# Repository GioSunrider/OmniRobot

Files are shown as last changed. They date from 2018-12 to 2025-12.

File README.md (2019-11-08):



# OmniRobot
Diseño e implementación de un robot omnidireccional para fines de entretenimiento. Proyecto de Final de Grado de Ingeniería Electrónica Industrial y Automática por la Universidad Carlos III de Madrid. 

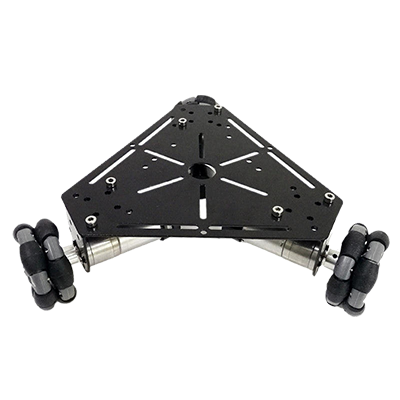
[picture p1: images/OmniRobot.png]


## BOM (Build Of Materials)

### Three Wheel Robot

* [100:1 Metal Gearmotor 37Dx57L mm](https://www.pololu.com/product/1106/specs)
* [Pololu Dual MC33926 Motor Driver Carrier](https://www.pololu.com/product/1213)
* [Pro Micro - 5V/16MHz](https://www.sparkfun.com/products/12640)
* [Omni Wheel 40x28mm Plástico](https://hobbyking.com/es_es/40x28mm-plastic-omni-wheel-2pcs-bag.html)
* Partes Impresas en **PETG** de [Fiberlogy](https://fiberlogy.com/en/fiberlogy-filaments/filament-pet-g/)
* [Laser Diodo 5V](http://es.aliexpress.com/item/2009851151.html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,searchweb201602_1,searchweb201603_55)
* [Convertidor DC-DC 5V](https://es.aliexpress.com/item/33011856834.html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,searchweb201602_1,searchweb201603_55)
* [Servo motor 90º](https://es.aliexpress.com/item/32958137557.html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,searchweb201602_1,searchweb201603_55) 

### Four Wheel Robot

* [30:1 Metal Gearmotor 37Dx57L mm](https://www.pololu.com/product/4742)
* [Pololu Dual MC33926 Motor Driver Carrier](https://www.pololu.com/product/1213)
* [Pro Micro - 5V/16MHz](https://www.sparkfun.com/products/12640)
* Partes Impresas en **PETG** de [Fiberlogy](https://fiberlogy.com/en/fiberlogy-filaments/filament-pet-g/)
* [Laser Diodo 5V](http://es.aliexpress.com/item/2009851151.html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,searchweb201602_1,searchweb201603_55)
* [Convertidor DC-DC 5V](https://es.aliexpress.com/item/33011856834.html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,searchweb201602_1,searchweb201603_55)
* [Servo motor 90º](https://es.aliexpress.com/item/32958137557.html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,searchweb201602_1,searchweb201603_55) 

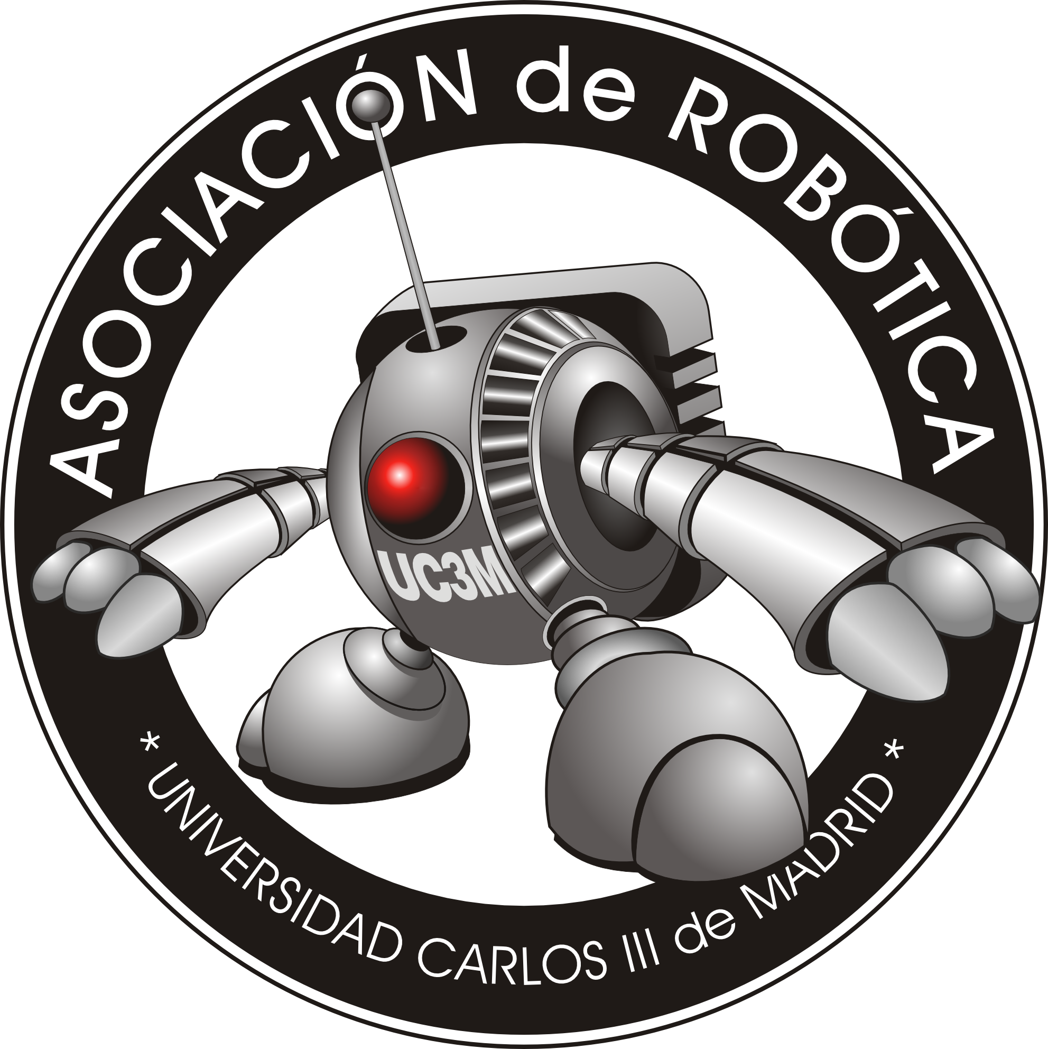
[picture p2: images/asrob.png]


## Contributors

 - Tutored by [@David-Estevez](https://github.com/David-Estevez)
 - [Asociación de Robótica de la Universidad Carlos III de Madrid](https://asrob.uc3m.es/)

## License 



This robot is licensed under a [Creative Commons Attribution-ShareAlike 4.0 International License](http://creativecommons.org/licenses/by-sa/4.0/). Please read the LICENSE files for more details.

Este robot tiene una licencia [Creative Commons Attribution-ShareAlike 4.0 International License](http://creativecommons.org/licenses/by-sa/4.0/). Por favor, lea los ficheros LICENSE para más detalles

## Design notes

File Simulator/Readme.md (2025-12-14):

1. Instalar Processing:

  Descarga Processing desde https://processing.org/download
  
  Instálalo en tu computadora

2. Ejecutar el simulador:

  Copia el código del simulador en un nuevo sketch de Processing
  
  Guarda el sketch con nombre "Robot3W_Simulador"
  
  Haz clic en el botón "Run" (triángulo)

3. Probar controles:

  Usa WASD para mover el robot
  
  Q/E para rotar
  
  ESPACIO para activar motores
  
  X para desactivar
  
  L para láser
  
  R para reset

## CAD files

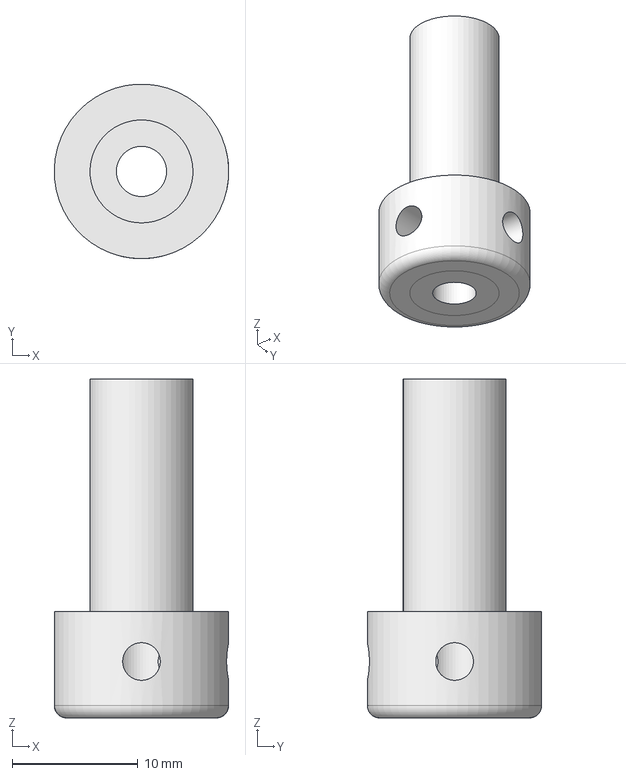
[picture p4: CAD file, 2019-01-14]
parts/Acoplamiento Motores (1)/AcoplamientoParte1.FCStd
13.9 x 13.9 x 27.0 mm

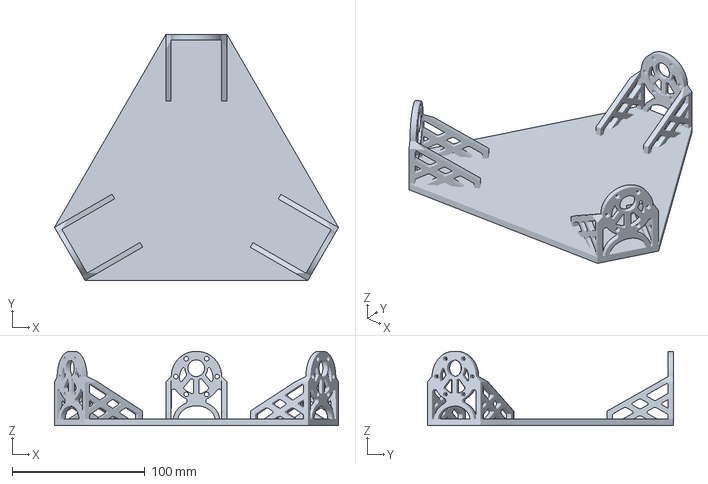
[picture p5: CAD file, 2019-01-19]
parts/Chasis (1)/ChasisV2_repaired.3mf
213.7 x 185.1 x 56.0 mm

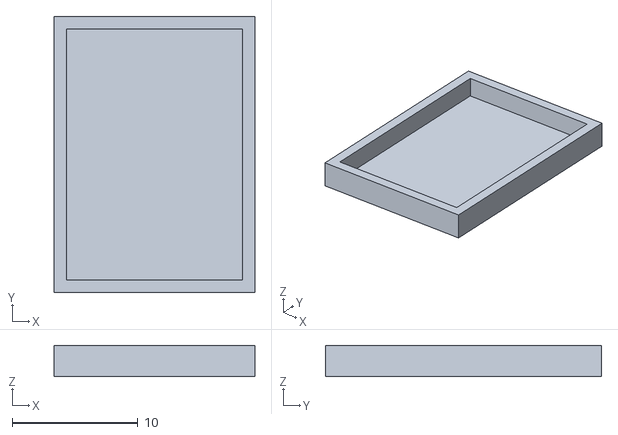
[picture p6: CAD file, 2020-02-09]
parts/Parts_Final/Disipador_BWP4.stl
16.0 x 22.0 x 2.50

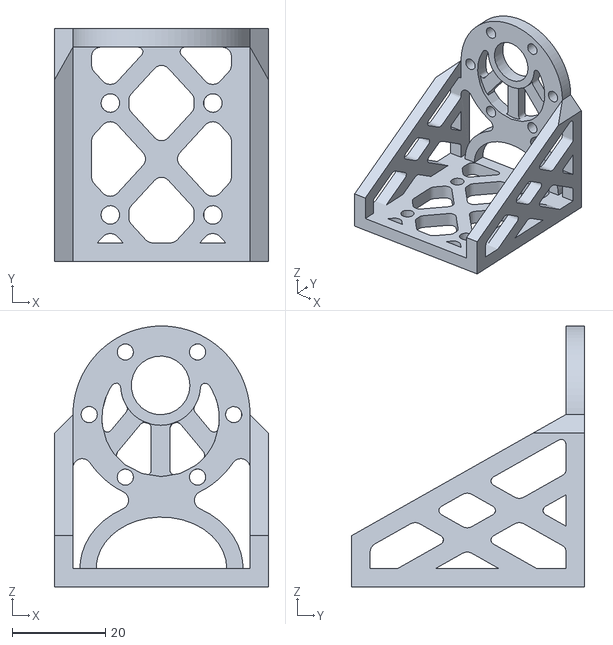
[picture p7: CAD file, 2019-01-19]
parts/Chasis (1)/Motor Holder V2.stl
46.0 x 50.0 x 56.0

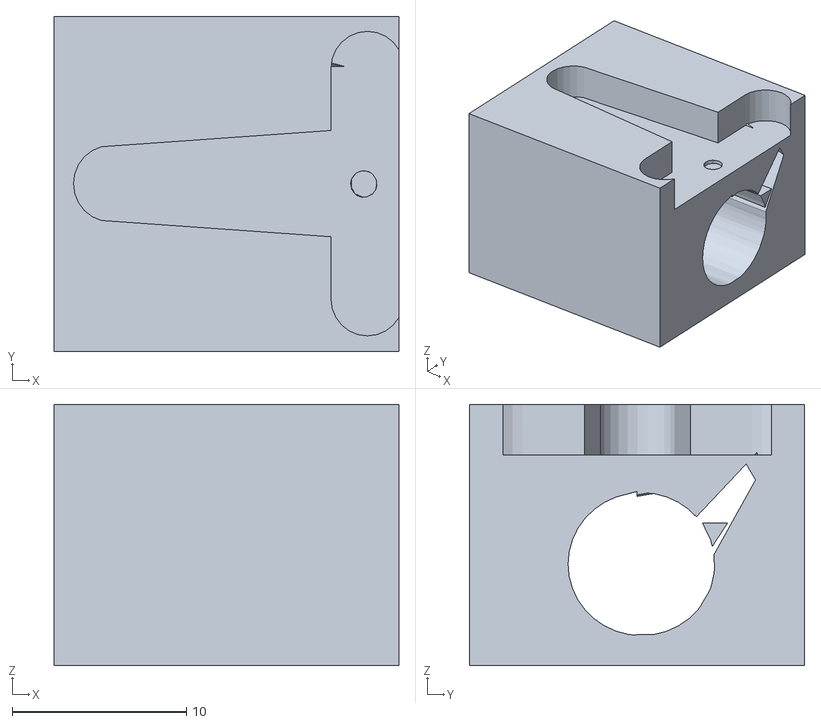
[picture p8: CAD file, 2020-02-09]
parts/Parts_Final/Laser_servo_Mount.stl
19.8 x 19.2 x 15.0

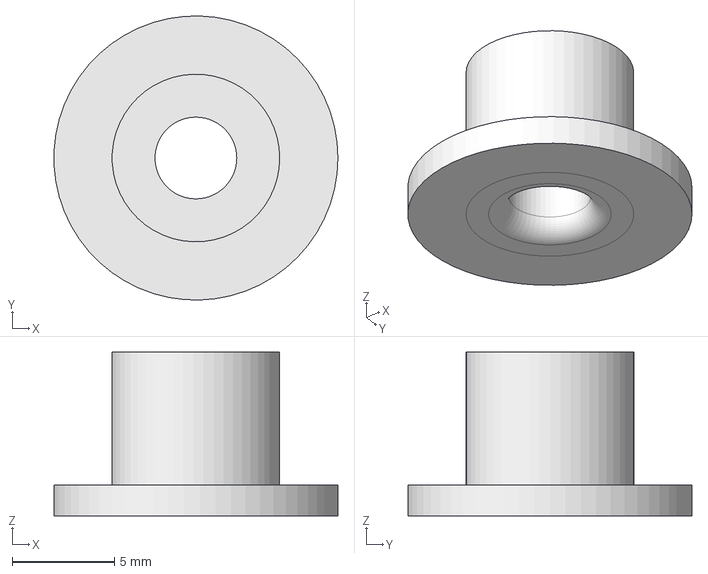
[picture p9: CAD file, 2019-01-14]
parts/Acoplamiento Motores (1)/AcoplamientoParte2.FCStd
13.9 x 13.9 x 8.00 mm

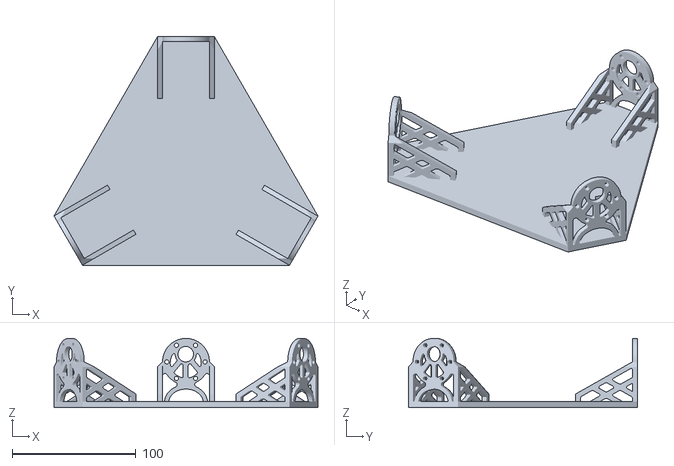
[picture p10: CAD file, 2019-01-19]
parts/Chasis (1)/ChasisV2.stl
213.7 x 185.1 x 56.0

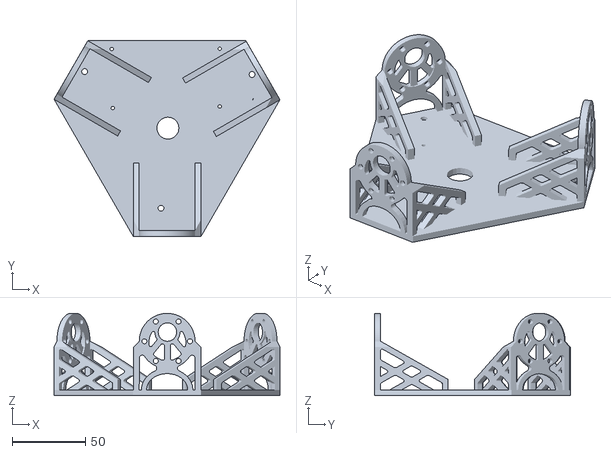
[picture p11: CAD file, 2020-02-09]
parts/Parts_Final/OmniRobot_3W_Botom.stl
153.8 x 133.1 x 56.0

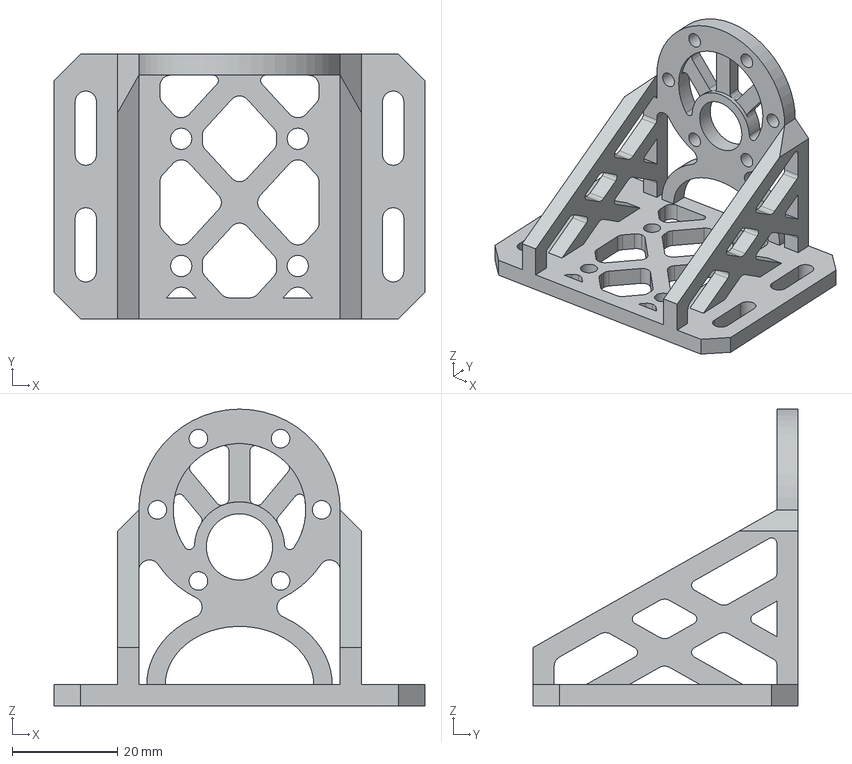
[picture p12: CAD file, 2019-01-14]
parts/Chasis (1)/MotorV1.stp
70.0 x 50.0 x 56.0 mm

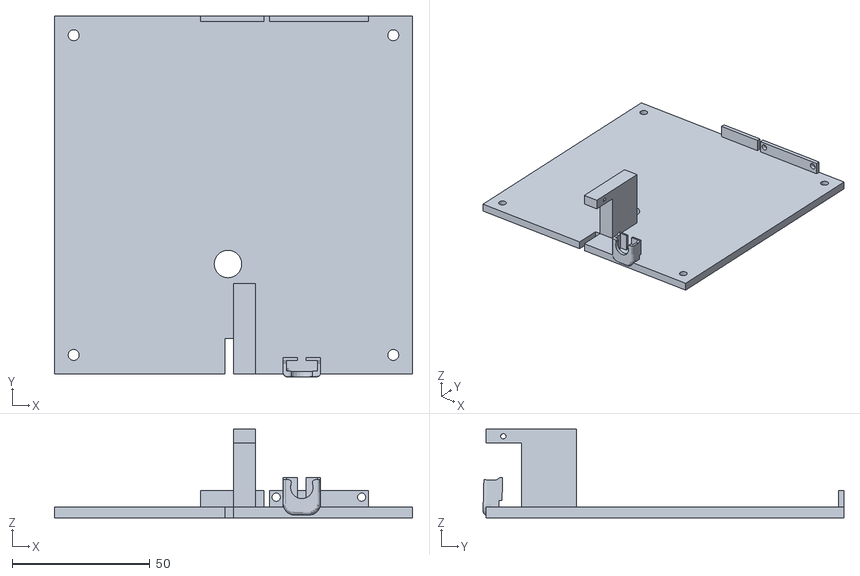
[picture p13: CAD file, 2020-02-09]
parts/Parts_Final/Omnirobot_4W_TOP.stl
130.0 x 131.0 x 32.2

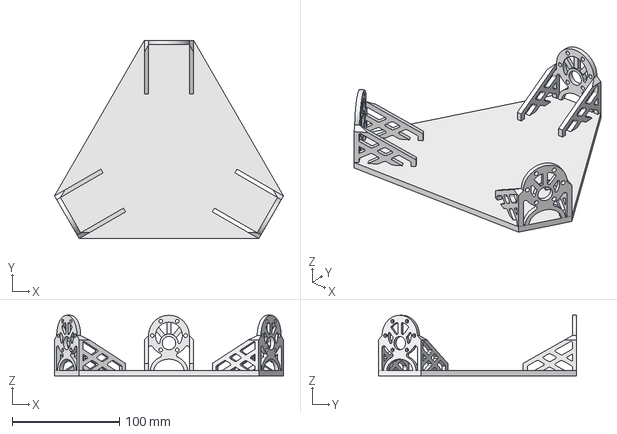
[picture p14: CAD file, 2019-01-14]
parts/Chasis (1)/ChasisV1.FCStd
213.6 x 185.1 x 56.5 mm

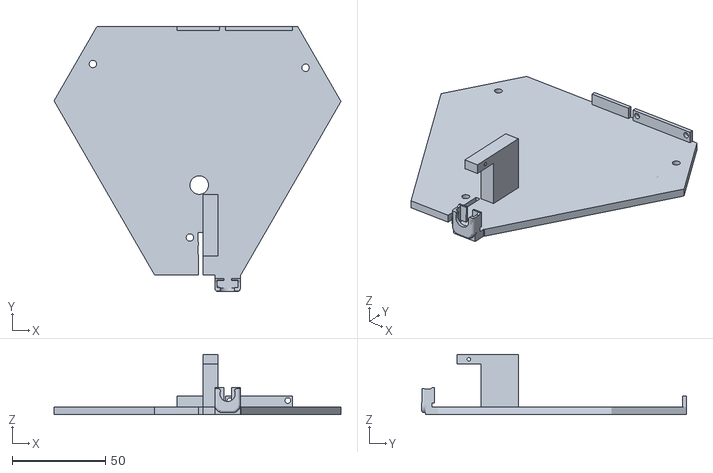
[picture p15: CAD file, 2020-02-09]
parts/Parts_Final/OmniRobot_3W_Top.stl
153.8 x 142.0 x 32.2

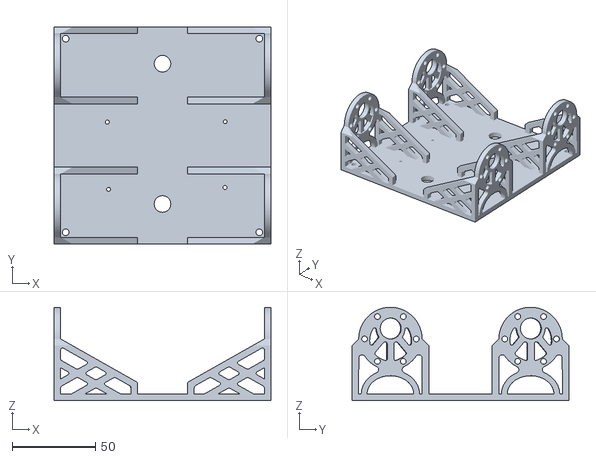
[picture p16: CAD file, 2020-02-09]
parts/Parts_Final/OmniRobot_4W_Bottom.stl
130.0 x 130.0 x 56.0

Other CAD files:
parts/Acoplamiento Motores (1)/acoplamiento1.stl
parts/Acoplamiento Motores (1)/acoplamiento2.stl
parts/Chasis (1)/motorV1.stl

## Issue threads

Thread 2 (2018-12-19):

Diseño inicial 3D del chasis

GioSunrider, 2018-12-19:
Se tiene que decidir la forma del coche, para ello es necesario la decision de 3 o 4 ruedas. Una vez elegido, se debe comenzar con el diseño en 3D. Se propone imprmirlo en PETG ya que aguanta mas los golpes.

GioSunrider, 2018-12-20:
Se realizan las siguientes propuestas de diseño:

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

David-Estevez, 2018-12-21:
Yo empezaría por la solución de 3 ruedas, que creo que nos daría las siguentes ventajas:

* Menos motores
* Menos consumo
* Más barato

El único (pequeño) inconveniente es que el control será ligeramente más complicado, pero el control es algo que ya está resuelto por otras personas.

GioSunrider, 2018-12-21:
Si, yo tambien creia lo mismo. Y si nos venimos arriba hacer un segundo pero de 4 ruedas, hacer el chasis no cuesta nada y como se imprime....

GioSunrider, 2018-12-28:
Se ha realizado la opcion uno, diseñada en FreeCad. y se ha subido al repo aa8b9a0, queda, cuando se encuentren motores, realizar los agujeros correspondientes para encajar en el propio chasis.

GioSunrider, 2019-01-14:
Se ha realizado un primer diseño con el soporte para motores, subido en 383bda1.

GioSunrider, 2019-01-21:
La impresion del chasis V2.0  ha sido un exito, tal y como se muestra en la imagen. Se han solventado los errores de la anterior impresion.

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

GioSunrider, 2019-03-10:
como se muestra en #4 la colocacion del motor en el chasis es perfecta, habra que hacer futuros rediseños para la colocacion del resto de cosas, pero este queda como funcional.

Closed 2019-03-10.

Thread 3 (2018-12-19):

Colocar las ruedas en el motor

GioSunrider, 2018-12-19:
Actualmente se dispone de las siguientes ruedas:

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

Aparentemente no hay manera de colocar el eje de las ruedas en un motor, por lo que hay que investigar como se podria realizar.

GioSunrider, 2018-12-20:
Se han encontrado la siguiente forma de encajar las ruedas en el motor, al parecer es como una tuerca en la que encaja el motor y se fija con una arandela y un tornillo.

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

GioSunrider, 2018-12-20:
Es un acoplamiento, 8mm to 4mm.

David-Estevez, 2018-12-21:
Es posible que esos funcionen, pero son casi más caros que la rueda suelta :open_mouth:

Tendremos que buscar una alternativa más barata en Aliexpress.

GioSunrider, 2018-12-21:
Me di cuenta del precio, pero no he encontrado otro redondo, ya que el resto son todos con cabezal hexagonal.

GioSunrider, 2018-12-25:
Por mucho que busco no encuentro más sujeciones que sean acordes a las dimensiones y al tipo de rueda 😭

GioSunrider, 2019-01-12:
vale he encontrado [este modelo mas barato](https://es.aliexpress.com/store/product/4mm-Aluminum-Mounting-Coupling-Universal-Hub-For-48mm-Mecanum-Omni-Wheel-Omnidirectional-Wheels-For-DIY-Robot/3619085_3286238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,searchweb201602_4_10065_10068_10890_10547_319_10546_317_10548_10696_453_10084_454_10083_10618_431_10307_10820_10303_537_536_10059_10884_10887_100031_321_322_10103,searchweb201603_51,ppcSwitch_0&algo_expid=f1210d98-d417-433c-8796-cd7f73e7d2c7-19&algo_pvid=f1210d98-d417-433c-8796-cd7f73e7d2c7&transAbTest=ae803_4) y [este otro](https://es.aliexpress.com/store/product/1set-Metal-Plastic-Coupling-Set-For-48mm-58mm-Mecanum-Omni-Wheel-For-Robot-Kit-And-Servo/3619085_32856499736.html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,searchweb201602_4_10065_10068_10890_10547_319_10546_317_10548_10696_453_10084_454_10083_10618_431_10307_10820_10303_537_536_10059_10884_10887_100031_321_322_10103,searchweb201603_51,ppcSwitch_0&algo_expid=4dd70a8f-cc74-419a-85d5-d84dba4e7ebe-31&algo_pvid=4dd70a8f-cc74-419a-85d5-d84dba4e7ebe&transAbTest=ae803_4) mas o menos por el mismo precio.

GioSunrider, 2019-01-14:
Se ha realizado una prueba de concepto imprimiendo en PLA y colocando los acoplamientos en la rueda, tal y como se muestran en las fotografias.

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

La rueda queda bien sujeta y daria la prueba como satisfactoria.
Para la prueba se han diseñado los acoplamientos, y se han parametrizado para su facilidad de cambio de diametros y ajuste posterior. Las piezas se subiran al repo.
El proximo paso seria imprimirlo en PETG que ganariamos resistencia mecanica.

GioSunrider, 2019-01-14:
Se han subido los archivos  154da56

GioSunrider, 2019-01-14:
Se han impreso los adaptadores en PETG, cuando estén instalados en las ruedas se podrá dar por cerrada la issue.

GioSunrider, 2019-02-13:
Para evitar la rotacion hace falta colocar unas juntas de goma para que no deslice.

GioSunrider, 2019-03-10:
Se tiene que rediseñar la pieza de sujecion dado que el eje del motor es bastante superior. Al estar la pieza hecha parametrica no sera mucho problema.

GioSunrider, 2019-05-23:
Se han impreso unos acomplamientos en PETG actualmente colocados junto con dos juntas cada uno para que no deslice, tambien se han impreso en TPU para probar el resultado.

Closed 2019-05-23.

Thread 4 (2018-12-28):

Busqueda de Motores

GioSunrider, 2018-12-28:
Es necesario buscar el modelo de motores que se instalen. Como se menciona en #2 para rematar el chasis, ademas es importante tener en cuenta #3

GioSunrider, 2018-12-28:
Una aproximacion de moteres pueden ser [estos](https://www.pololu.com/product/2286) aunque sin encoder, ya que en principio no es necesario.

GioSunrider, 2019-01-20:
[Este motor](https://m.banggood.com/DC-12V-300RPM-Geared-Motor-High-Torque-37GB-550-Gear-Reducer-Motor-p-1068575.html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) es un gran firme candidato. Motor de 12V 300rpm y alto par.

GioSunrider, 2019-01-31:
[Este Motor sera EL ELEGIDO](https://www.banggood.com/es/DC-6V-90RPM-Geared-Motor-37GB-550-High-Torque-Gear-Reducer-Motor-p-1068574.html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)

David-Estevez, 2019-02-03:
Para poder avanzar habría que comprar al menos 1 motor... puedo preguntar en el departamento a ver si han abierto de nuevo la veda para los TFGs...

GioSunrider, 2019-02-04:
Genial, pues ya me dirás la confirmación.

GioSunrider, 2019-02-13:
[Este motor](https://www.pololu.com/product/1106/specs) es el mismo del anterior pero de un distribuidor oficial.

GioSunrider, 2019-03-10:
Se ha obtenido el motor, via departamento y se ha instalado en el chasis.

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

Closed 2019-03-10.

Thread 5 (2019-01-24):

Cinematica de movimiento

GioSunrider, 2019-01-24:
Estudiar la cinematica del movimiento para una posterior programacion.
Estos dibujos ayudaran a ello.

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

David-Estevez, 2019-01-26:
No es que ayuden, es que el de en medio ya te está diciendo cuál es la cinemática inversa del robot :joy:

David-Estevez, 2019-01-27:
https://en.wikipedia.org/wiki/Reinventing_the_wheel

GioSunrider, 2019-01-28:
No hay tanta informacion, pero por pasarla a codigo no era mas que ver que hay primero. reeeellaaaax que no soy tan loco.

GioSunrider, 2019-01-28:
Creo que ahora mismo te voy a hacer un pedestal 🤣

GioSunrider, 2019-05-23:
Se ha actualizado el codigo usado en el robot en 86dccc9  que controla los movimientos.

Closed 2019-05-23.

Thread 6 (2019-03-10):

Control del motor

GioSunrider, 2019-03-10:
Junto con el Driver y un arduino mirco se ha comenzado al control del motor.

GioSunrider, 2019-03-10:
Para ello se va a usar la [siguiente libreria](https://github.com/pololu/dual-mc33926-motor-shield)

GioSunrider, 2019-05-23:
El motor se controla perfectamente, se subira un esquema de conexiones y puenteado.

GioSunrider, 2019-08-07:
continua en #14

Closed 2019-08-07.

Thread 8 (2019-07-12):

Fotodiodos

GioSunrider, 2019-07-12:
Pruebas con fotodiodos para la recepcion en arduino. Ejemplo en a siguiente imagen.
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

GioSunrider, 2019-07-12:
Los fotodiodos usados seran BPW34.

GioSunrider, 2019-08-07:
Se ha diseñado una placa en la que se tienen que subir los archivos y los diseños.

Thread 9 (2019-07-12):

LDR

GioSunrider, 2019-07-12:
Pruebas con LDR para la recepcion de los disparos. Ejemplo en la siguiente imagen.
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

GioSunrider, 2020-02-09:
Se descarto la idea por no necesitar de un sistema exacto de disparo.

Closed 2020-02-09.

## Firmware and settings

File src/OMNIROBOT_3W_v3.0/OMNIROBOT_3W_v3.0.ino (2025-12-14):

/*
 * Designed by @GioSunrider
 * TFG OmniRobot V0.3
 * CC-BY-SA
 *
 */

// ------------------------------------------------------------------------------------------
//    Esquema Coche
// ------------------------------------------------------------------------------------------ 
//       __ A
//     /    \ 
//    /      \   
// B |________| C
     
// ------------------------------------------------------------------------------------------
// Librerias
// ------------------------------------------------------------------------------------------

#include <math.h>
#include <FlySkyIBus.h>

// ------------------------------------------------------------------------------------------
// DEFINICION PINES Pololu Dual MC33926 Motor Driver Shield
//              ARDUINO MICRO PRO
// ------------------------------------------------------------------------------------------

#define ENABLE  2

#define MotorA1 4
#define MotorA2 5

#define MotorB1 7
#define MotorB2 8

#define MotorC1 10
#define MotorC2 16

#define PWMA    3
#define PWMB    6
#define PWMC    9

// ------------------------------------------------------------------------------------------
// DEFINICION PINES Emision y Recepcion Laser
// ------------------------------------------------------------------------------------------

#define analogInPin A3       // Pin analogico para la lectura del Fototransistor
#define Servo_Laser 3        // Pin para el servo laser (CONFLICTO CON PWMA - CORREGIDO)
#define LED_Golpe A2         // Led que ilumina cuando ha recibido un golpe
#define Laser 1              // Control del Laser

// ------------------------------------------------------------------------------------------
// DEFINICION PINES Entrada iBus
//       Emisora Flysky FS-i6
//      Receptor Flysky FS-X6B
// ------------------------------------------------------------------------------------------

float Channel_1;  // Ahead and back (Y)
float Channel_2;  // Left and Right (X)
float Channel_3;  // Shooter Up-Down
float Channel_4;  // Rotation (W)
float Channel_5;  // ENABLE
float Channel_6;  // Laser

// ------------------------------------------------------------------------------------------
// Constantes y Variables
// ------------------------------------------------------------------------------------------

const float sqrt3o2 = sqrt(3.0)/2.0;
const float arms_size = 110.0; // mm
const float wheel_radius = 20.5; // mm (41/2)

float speed_A = 0;
float speed_B = 0;
float speed_C = 0;

const int thresholdMIN = 90;   // Valor Umbral Minimo de Recepcion del fotodiodo
const int thresholdMAX = 120;  // Valor Umbral Maximo de Recepcion del fotodiodo

int sensorValue = 0;        // Valor del sensor
int lives = 10;             // Numero de "vidas" que tiene
unsigned long lastHitTime = 0;  // Para evitar múltiples detecciones rápidas
const unsigned long hitDebounceTime = 500; // ms

// Variables para el servo PWM
unsigned long servoPulseStart = 0;
int servoAngle = 90;
bool servoPulseActive = false;
const unsigned long servoPeriod = 20000; // 20ms para servo (50Hz)

// ------------------------------------------------------------------------------------------
// Setup
// -----------------------------------------------------------------------------------------

void setup(){
  // IMPORTANTE: Inicializar Serial1 para IBus (Arduino Micro Pro usa Serial1 para pines 0/1)
  Serial1.begin(115200);
  IBus.begin(Serial1);

  // Serial para debug
  Serial.begin(9600);

  pinMode(ENABLE, OUTPUT);

  // Configurar pines de motor PWM
  pinMode(PWMA, OUTPUT);
  pinMode(PWMB, OUTPUT);
  pinMode(PWMC, OUTPUT);

  // Configurar pines de dirección de motor
  pinMode(MotorA1, OUTPUT);
  pinMode(MotorA2, OUTPUT);
  pinMode(MotorB1, OUTPUT);
  pinMode(MotorB2, OUTPUT);
  pinMode(MotorC1, OUTPUT);
  pinMode(MotorC2, OUTPUT);

  // Configurar pines de sensores y actuadores
  pinMode(analogInPin, INPUT);
  pinMode(LED_Golpe, OUTPUT);
  pinMode(Laser, OUTPUT);
  pinMode(Servo_Laser, OUTPUT);
  
  // Inicializar todos los pines en estado seguro
  digitalWrite(ENABLE, LOW);
  digitalWrite(Laser, LOW);
  digitalWrite(LED_Golpe, LOW);
  
  // Configurar PWM a 0
  analogWrite(PWMA, 0);
  analogWrite(PWMB, 0);
  analogWrite(PWMC, 0);
  
  // Configurar pines de dirección a LOW
  digitalWrite(MotorA1, LOW);
  digitalWrite(MotorA2, LOW);
  digitalWrite(MotorB1, LOW);
  digitalWrite(MotorB2, LOW);
  digitalWrite(MotorC1, LOW);
  digitalWrite(MotorC2, LOW);
  
  // Configurar servo a posición central
  servoAngle = 90;
  
  Serial.println("Robot 3W Inicializado");
}

// ------------------------------------------------------------------------------------------
// Funciones para control de motores (3 ruedas)
// ------------------------------------------------------------------------------------------

void set_motor_speed(int motor, float spd) {
  int pwmValue = constrain(abs(spd), 0, 200);
  pwmValue = map(pwmValue, 0, 200, 0, 255);
  
  switch (motor) {
    case 0: // Motor A (Frontal/Trasero)
      if (spd > 1) { // Adelante
        digitalWrite(MotorA1, HIGH);
        digitalWrite(MotorA2, LOW);
        analogWrite(PWMA, pwmValue);
      } else if (spd < -1) { // Atrás
        digitalWrite(MotorA1, LOW);
        digitalWrite(MotorA2, HIGH);
        analogWrite(PWMA, pwmValue);
      } else { // Parar
        digitalWrite(MotorA1, LOW);
        digitalWrite(MotorA2, LOW);
        analogWrite(PWMA, 0);
      }
      break;
      
    case 1: // Motor B (Izquierdo)
      if (spd > 1) {
        digitalWrite(MotorB1, HIGH);
        digitalWrite(MotorB2, LOW);
        analogWrite(PWMB, pwmValue);
      } else if (spd < -1) {
        digitalWrite(MotorB1, LOW);
        digitalWrite(MotorB2, HIGH);
        analogWrite(PWMB, pwmValue);
      } else {
        digitalWrite(MotorB1, LOW);
        digitalWrite(MotorB2, LOW);
        analogWrite(PWMB, 0);
      }
      break;
      
    case 2: // Motor C (Derecho)
      if (spd > 1) {
        digitalWrite(MotorC1, HIGH);
        digitalWrite(MotorC2, LOW);
        analogWrite(PWMC, pwmValue);
      } else if (spd < -1) {
        digitalWrite(MotorC1, LOW);
        digitalWrite(MotorC2, HIGH);
        analogWrite(PWMC, pwmValue);
      } else {
        digitalWrite(MotorC1, LOW);
        digitalWrite(MotorC2, LOW);
        analogWrite(PWMC, 0);
      }
      break;
  }
}

// Movimiento omnidireccional para robot de 3 ruedas
void vector_movement(float X, float Y, float W) {
  // Fórmula corregida para robot de 3 ruedas en configuración triangular
  // Ruedas a 120 grados: A(0°), B(120°), C(240°)
  
  // Componentes de velocidad para cada rueda
  speed_A = (-sin(0) * X + cos(0) * Y) + (arms_size * W);          // Rueda A (0°)
  speed_B = (-sin(2.0944) * X + cos(2.0944) * Y) + (arms_size * W); // Rueda B (120° = 2.0944 rad)
  speed_C = (-sin(4.1888) * X + cos(4.1888) * Y) + (arms_size * W); // Rueda C (240° = 4.1888 rad)
  
  // Aplicar factor de escala del radio de la rueda
  speed_A /= wheel_radius;
  speed_B /= wheel_radius;
  speed_C /= wheel_radius;
  
  // Normalizar velocidades si alguna excede el máximo
  float max_speed = max(max(abs(speed_A), abs(speed_B)), abs(speed_C));
  if (max_speed > 200) {
    float scale = 200.0 / max_speed;
    speed_A *= scale;
    speed_B *= scale;
    speed_C *= scale;
  }
  
  // Aplicar velocidades a los motores
  set_motor_speed(0, speed_A);
  set_motor_speed(1, speed_B);
  set_motor_speed(2, speed_C);
}

// ------------------------------------------------------------------------------------------
// Funciones para servo (generación de señal PWM manual)
// ------------------------------------------------------------------------------------------

void updateServo() {
  unsigned long currentMicros = micros();
  
  if (!servoPulseActive) {
    // Comenzar nuevo pulso
    digitalWrite(Servo_Laser, HIGH);
    servoPulseStart = currentMicros;
    servoPulseActive = true;
  } else {
    // Terminar pulso después del tiempo apropiado
    unsigned long pulseWidth = map(servoAngle, 0, 180, 500, 2500); // 0.5ms a 2.5ms
    
    if (currentMicros - servoPulseStart >= pulseWidth) {
      digitalWrite(Servo_Laser, LOW);
      
      // Si ha pasado un período completo, reiniciar
      if (currentMicros - servoPulseStart >= servoPeriod) {
        servoPulseActive = false;
      }
    }
  }
}

void setServoAngle(int angle) {
  servoAngle = constrain(angle, 0, 180);
}

// ------------------------------------------------------------------------------------------
// Función para detección de golpes
// ------------------------------------------------------------------------------------------

void checkHit() {
  sensorValue = analogRead(analogInPin);
  unsigned long currentTime = millis();
  
  if (sensorValue > thresholdMIN && sensorValue < thresholdMAX) {
    if (currentTime - lastHitTime > hitDebounceTime) {
      lives = max(0, lives - 1); // Asegurar que no sea negativo
      lastHitTime = currentTime;
      
      // Parpadear LED para indicar golpe
      for (int i = 0; i < 3; i++) {
        digitalWrite(LED_Golpe, HIGH);
        delay(100);
        digitalWrite(LED_Golpe, LOW);
        delay(100);
      }
      
      Serial.print("Golpe recibido! Vidas restantes: ");
      Serial.println(lives);
    }
  }
}

// ------------------------------------------------------------------------------------------
// Función para leer y mapear canales IBus
// ------------------------------------------------------------------------------------------

void readIBusChannels() {
  IBus.loop();
  
  // Leer canales IBus (rango 1000-2000)
  int ch1_raw = IBus.readChannel(0);
  int ch2_raw = IBus.readChannel(1);
  int ch3_raw = IBus.readChannel(2);
  int ch4_raw = IBus.readChannel(3);
  int ch5_raw = IBus.readChannel(4);
  int ch6_raw = IBus.readChannel(5);
  
  // Mapear a rangos útiles
  Channel_1 = mapFloat(ch1_raw, 1000, 2000, -100.0, 100.0); // Y (adelante/atrás)
  Channel_2 = mapFloat(ch2_raw, 1000, 2000, -100.0, 100.0); // X (izquierda/derecha)
  Channel_3 = mapFloat(ch3_raw, 1000, 2000, 0.0, 180.0);    // Servo (0-180 grados)
  Channel_4 = mapFloat(ch4_raw, 1000, 2000, -10.0, 10.0);   // W (rotación)
  Channel_5 = ch5_raw;  // ENABLE (1000-2000)
  Channel_6 = ch6_raw;  // Laser (1000-2000)
  
  // Debug opcional
  static unsigned long lastDebug = 0;
  if (millis() - lastDebug > 1000) {
    Serial.print("Canales: ");
    Serial.print(Channel_1); Serial.print(", ");
    Serial.print(Channel_2); Serial.print(", ");
    Serial.print(Channel_3); Serial.print(", ");
    Serial.print(Channel_4); Serial.print(", ");
    Serial.print(Channel_5); Serial.print(", ");
    Serial.println(Channel_6);
    lastDebug = millis();
  }
}

float mapFloat(float x, float in_min, float in_max, float out_min, float out_max) {
  return (x - in_min) * (out_max - out_min) / (in_max - in_min) + out_min;
}

// ------------------------------------------------------------------------------------------
// Loop principal
// ------------------------------------------------------------------------------------------

void loop() {
  // Actualizar servo continuamente
  updateServo();
  
  // Leer valores del receptor IBus
  readIBusChannels();
  
  // Controlar laser
  if (Channel_6 > 1500) { // Umbral en el centro del rango
    digitalWrite(Laser, HIGH);
  } else {
    digitalWrite(Laser, LOW);
  }
  
  // Verificar golpes
  checkHit();
  
  // Control principal si hay vidas
  if (lives > 0) {
    if (Channel_5 > 1500) { // ARMADO de los motores
      digitalWrite(ENABLE, HIGH);
      
      // Aplicar movimiento omnidireccional
      vector_movement(Channel_2, Channel_1, Channel_4);
      
      // Actualizar posición del servo
      setServoAngle((int)Channel_3);
    } else {
      // Desarmado - detener todos los motores
      digitalWrite(ENABLE, LOW);
      set_motor_speed(0, 0);
      set_motor_speed(1, 0);
      set_motor_speed(2, 0);
    }
  } else {
    // Sin vidas - desactivar todo
    digitalWrite(ENABLE, LOW);
    digitalWrite(Laser, LOW);
    set_motor_speed(0, 0);
    set_motor_speed(1, 0);
    set_motor_speed(2, 0);
    
    // LED de alerta intermitente
    static unsigned long lastBlink = 0;
    if (millis() - lastBlink > 500) {
      digitalWrite(LED_Golpe, !digitalRead(LED_Golpe));
      lastBlink = millis();
    }
  }
  
  // Pequeña pausa para estabilidad
  delay(10);
}

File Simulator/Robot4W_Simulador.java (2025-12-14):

// Robot Omnidireccional 4W - Simulador
// Processing 3.5.4 o superior
// Compatible con código OMNIROBOT_4W_v3.0.ino

import processing.serial.*;

Serial puerto;
PFont fuente;
boolean[] teclas = new boolean[256];
boolean robotActivo = false;
int vidas = 10;
float anguloServo = 90;
boolean laserEncendido = false;
boolean modoDebug = false;

// Variables del robot (configuración 4 ruedas)
float posX, posY;
float anguloRobot = 0;
float velocidad = 2.5;

// Variables de control
float joystickX = 0;
float joystickY = 0;
float joystickW = 0;

// Configuración de motores (4 ruedas en X)
float[] velocidadesMotor = new float[4];
// Posiciones de ruedas: A(arriba-izq), B(arriba-der), C(abajo-der), D(abajo-izq)
PVector[] posicionesRuedas = {
  new PVector(-1, -1),  // A
  new PVector(1, -1),   // B  
  new PVector(1, 1),    // C
  new PVector(-1, 1)    // D
};

// Configuración específica del robot 4W
float arms_size = 120; // mm (del código original)
float wheel_radius = 37; // mm (74/2 del código original)

void setup() {
  size(1100, 800);
  fuente = createFont("Arial", 16);
  textFont(fuente);
  
  // Configuración de puerto serial
  println("=== SIMULADOR ROBOT 4W OMNIDIRECCIONAL ===");
  println("Puertos seriales disponibles:");
  printArray(Serial.list());
  
  // Intentar conectar automáticamente
  for (int i = 0; i < Serial.list().length; i++) {
    if (Serial.list()[i].contains("usbmodem") || 
        Serial.list()[i].contains("COM") || 
        Serial.list()[i].contains("ttyACM") ||
        Serial.list()[i].contains("ttyUSB")) {
      try {
        puerto = new Serial(this, Serial.list()[i], 9600);
        puerto.bufferUntil('\n');
        println("Conectado a: " + Serial.list()[i]);
        break;
      } catch (Exception e) {
        println("Error conectando a " + Serial.list()[i]);
      }
    }
  }
  
  if (puerto == null) {
    println("Modo simulación pura - Sin conexión serial");
  }
  
  // Posición inicial
  posX = width/2;
  posY = height/2 - 100;
  
  // Inicializar teclas
  for (int i = 0; i < teclas.length; i++) {
    teclas[i] = false;
  }
  
  // Configuración de gráficos
  smooth();
  frameRate(60);
}

void draw() {
  background(25, 25, 35);
  
  // Actualizar controles
  actualizarControles();
  
  // Dibujar área de simulación principal
  dibujarAreaSimulacion();
  
  // Dibujar robot
  dibujarRobot4W();
  
  // Dibujar paneles de información
  dibujarPanelControl();
  dibujarPanelEstado();
  dibujarPanelMotores();
  
  // Dibujar vista superior (diagrama de omni)
  dibujarVistaSuperior();
  
  // Enviar comandos si está conectado
  if (puerto != null && puerto.active()) {
    enviarComandosSerial();
  }
  
  // Actualizar simulación de movimiento
  actualizarSimulacion();
}

void actualizarControles() {
  // Resetear controles
  joystickX = joystickY = joystickW = 0;
  
  // Control de movimiento (WASD + QE para rotación)
  if (teclas['w'] || teclas['W']) joystickY = 100;
  if (teclas['s'] || teclas['S']) joystickY = -100;
  if (teclas['a'] || teclas['A']) joystickX = -100;
  if (teclas['d'] || teclas['D']) joystickX = 100;
  if (teclas['q'] || teclas['Q']) joystickW = -10;
  if (teclas['e'] || teclas['E']) joystickW = 10;
  
  // Control de activación (ESPACIO para activar, X para desactivar)
  if (teclas[' ']) {
    robotActivo = true;
  }
  if (teclas['x'] || teclas['X']) {
    robotActivo = false;
  }
  
  // Control de láser
  laserEncendido = teclas['l'] || teclas['L'];
  
  // Control de servo con teclas
  if (teclas['z'] || teclas['Z']) {
    anguloServo = max(anguloServo - 2, 0);
  }
  if (teclas['c'] || teclas['C']) {
    anguloServo = min(anguloServo + 2, 180);
  }
  
  // Reset con R
  if (teclas['r'] || teclas['R']) {
    resetSimulacion();
  }
  
  // Modo debug con F1
  if (teclas[112]) { // F1
    modoDebug = !modoDebug;
    teclas[112] = false; // Evitar toggle rápido
  }
  
  // Calcular velocidades de los motores (fórmula 4W)
  calcularVelocidades4W();
}

void calcularVelocidades4W() {
  // Fórmula original del código Arduino para 4 ruedas:
  // speed_A = ((Y)+(arms_size*W));
  // speed_B = ((-X)+(arms_size*W));
  // speed_C = ((-Y)+(arms_size*W));
  // speed_D = ((X)+(arms_size*W));
  
  // Aplicamos la fórmula
  velocidadesMotor[0] = (joystickY) + (arms_size * joystickW);  // A
  velocidadesMotor[1] = (-joystickX) + (arms_size * joystickW); // B
  velocidadesMotor[2] = (-joystickY) + (arms_size * joystickW); // C
  velocidadesMotor[3] = (joystickX) + (arms_size * joystickW);  // D
  
  // Normalizar a rango [-200, 200] como en el código Arduino
  float maxSpeed = 0;
  for (int i = 0; i < 4; i++) {
    maxSpeed = max(maxSpeed, abs(velocidadesMotor[i]));
  }
  
  if (maxSpeed > 200) {
    float factor = 200.0 / maxSpeed;
    for (int i = 0; i < 4; i++) {
      velocidadesMotor[i] *= factor;
    }
  }
}

void actualizarSimulacion() {
  if (robotActivo && vidas > 0) {
    // Movimiento omnidireccional puro (sin rotación del chasis)
    float movX = joystickX * 0.01 * velocidad;
    float movY = joystickY * 0.01 * velocidad;
    
    posX += movX;
    posY -= movY; // Invertir Y para coordenadas de pantalla
    
    // Rotación independiente
    anguloRobot += joystickW * 0.5;
    
    // Mantener dentro de límites
    posX = constrain(posX, 100, width - 100);
    posY = constrain(posY, 100, height - 300);
    
    // Detectar colisiones con obstáculos
    detectarColisiones();
  }
}

void detectarColisiones() {
  // Obstáculos fijos
  float[][] obstaculos = {
    {200, 200, 50},
    {width - 200, 200, 50},
    {width/2, height - 250, 60},
    {width/4, height/2, 40},
    {3*width/4, height/2, 40}
  };
  
  float radioRobot = 60;
  
  for (float[] obs : obstaculos) {
    float distancia = dist(posX, posY, obs[0], obs[1]);
    if (distancia < (radioRobot + obs[2])) {
      // Golpe detectado
      if (frameCount % 30 == 0) { // Cada medio segundo aprox
        vidas = max(0, vidas - 1);
      }
      
      // Empujar fuera del obstáculo
      float ang = atan2(posY - obs[1], posX - obs[0]);
      posX = obs[0] + cos(ang) * (radioRobot + obs[2] + 5);
      posY = obs[1] + sin(ang) * (radioRobot + obs[2] + 5);
    }
  }
}
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

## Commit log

2018-12-20 Correct mistakes
    @jgvictores notifico el error
2019-07-25 UPDATE NEW BOARD
2019-11-17 Servo laser update
2025-12-14 Refactor OMNIROBOT control logic and servo functions
    Updated robot control logic and improved servo handling.
2025-12-14 Add 3W omnidirectional robot simulator
    This file implements a 3-wheel omnidirectional robot simulator using Processing. It includes controls for movement, laser activation, and collision detection.
